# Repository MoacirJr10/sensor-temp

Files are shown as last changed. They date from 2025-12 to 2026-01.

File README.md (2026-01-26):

# Estação Híbrida de Monitoramento
### Monitoramento de Ar e Aquário com ESP8266

---

## Visão Geral
Estação de monitoramento inteligente baseada no **ESP8266 (Wemos D1 Mini)**, capaz de medir:

-  Temperatura e umidade do ar (DHT11)
-  Temperatura da água do aquário (DS18B20)
-  Hora e data (RTC + NTP)
-  Status de conexão WiFi

Todas as informações são exibidas em um **display LCD 20x4**.

---
## Conexões Elétricas

| Componente | Pino do Componente | Pino no Wemos D1 Mini | Nota Importante |
| --- | --- | --- | --- |
| **DS18B20 (Aquário)** | VCC (Vermelho) | 3.3V | Resistor **4.7kΩ** entre VCC e DATA |
| | GND (Preto) | GND | — |
| | DATA (Amarelo) | D3 | Protocolo **OneWire** |
| **DHT11 (Ar)** | VCC | 3.3V ou 5V | Funciona em ambas tensões |
| | GND | GND | — |
| | DATA | D4 | — |
| **LCD 20x4 I2C** | VCC | 5V | Melhor contraste |
| | GND | GND | — |
| | SDA | D2 | Comunicação I2C |
| | SCL | D1 | Comunicação I2C |
| **RTC DS1302** | VCC | 5V ou 3.3V | Depende do módulo |
| | GND | GND | — |
| | CLK | D5 | Clock |
| | DAT | D6 | Dados |
| | RST | D7 | Reset |

---

##  Galeria do Projeto
###  Case
<p align="center">
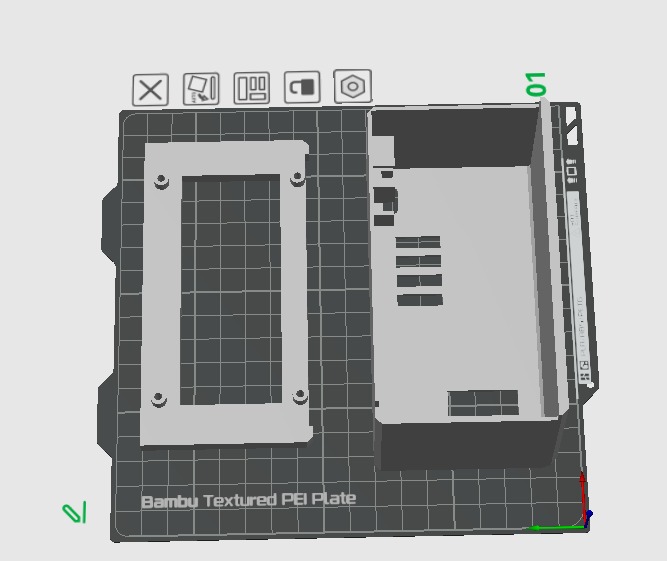
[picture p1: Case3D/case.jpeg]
  
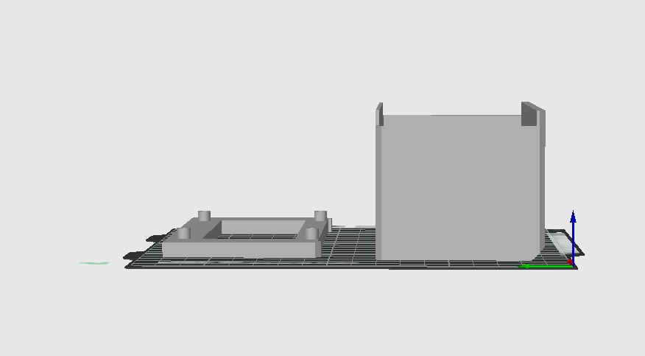
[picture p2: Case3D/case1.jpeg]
  
</p>

###  Detalhes 
<p align="center">
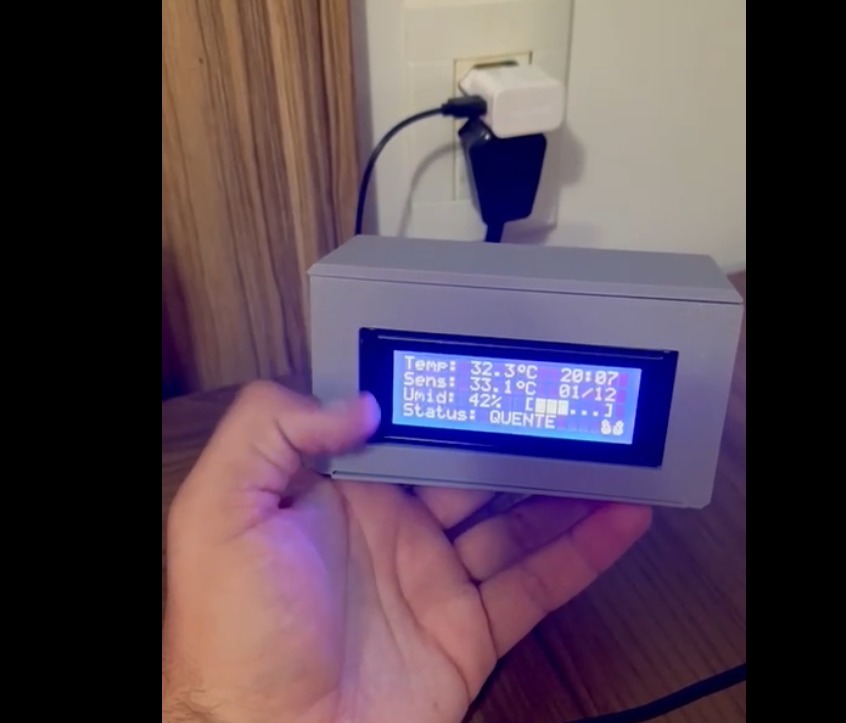
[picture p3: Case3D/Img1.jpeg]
  
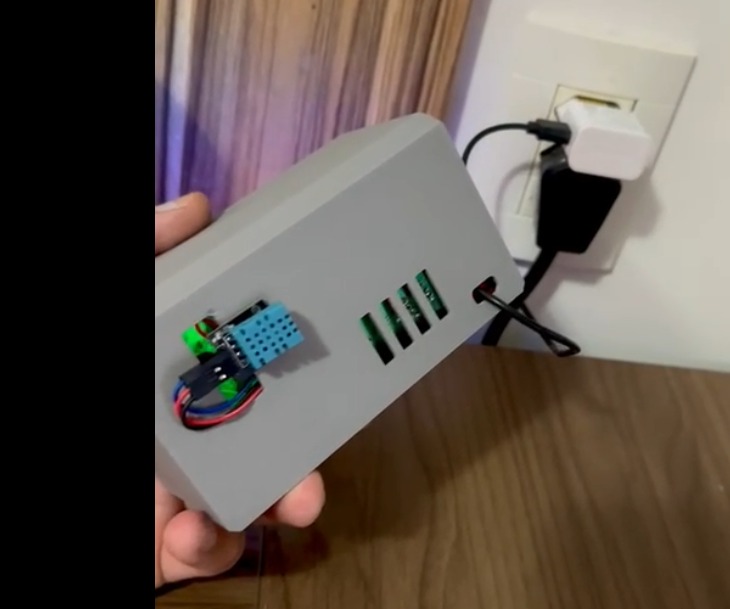
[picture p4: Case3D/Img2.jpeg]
  
</p>

---

##  Componentes Utilizados

| Componente | Função |
|---|---|
| Wemos D1 Mini (ESP8266) | Processamento e WiFi |
| Sensor DHT11 | Temperatura e umidade do ar |
| Sensor DS18B20 | Temperatura da água |
| Display LCD 20x4 I2C | Interface visual |
| RTC DS1302 | Data e hora |
| Resistor 4.7kΩ | Pull-up do DS18B20 |

---

##  Layout do Display LCD

| Linha | Conteúdo |
|-----|---|
| Linha 1 |  Temp. do Ar +  Hora |
| Linha 2 |  Temp. da Água +  Data |
| Linha 3 |  Umidade (%) + Barra |
| Linha 4 | Conforto +  WiFi + Emoji |

---

##  Pinagem – Wemos D1 Mini

| Pino | Ligação |
|----|---|
| D1 (SCL) | LCD I2C |
| D2 (SDA) | LCD I2C |
| D3 | DS18B20 (4.7kΩ → 3.3V) |
| D4 | DHT11 |
| D5 | RTC CLK |
| D6 | RTC DAT |
| D7 | RTC RST |

---

##  WiFi – Funcionamento Inteligente

| Recurso | Descrição |
|---|---|
| AP Temporário | `ESTACAO_AQUARIO` |
| Portal Ativo | 60 segundos |
| Modo Offline | Funciona sem WiFi |
| Reconexão | A cada 10 segundos |

---

##  Análise de Conforto

###  Temperatura do Ar
| Estado | Faixa |
|-----|---|
| FRIO | < 16 °C |
| NORMAL | 16–29 °C |
| QUENTE | > 29 °C |

###  Umidade
| Estado | Faixa |
|-----|---|
| Muito seco | < 30% |
| Normal | 30–75% |
| Muito úmido | > 75% |

---

##  Arquivos STL – Impressão 3D

 **Local:** `Case3D/stl/`

| Arquivo | Descrição |
|---|---|
| [`ArduBody.stl`](Case3D/stl/ArduBody.stl) | Corpo da estação |
| [`ArduLcdCover.stl`](Case3D/stl/ArduLcdCover.stl) | Moldura do LCD |

 Recomendações:
- Material: PLA ou PETG
- Infill: 20–30%
- Camada: 0.2 mm

---

##  Bibliotecas Necessárias

- DHT sensor library
- LiquidCrystal I2C
- Rtc by Makuna
- WiFiManager
- DallasTemperature
- OneWire

---

##  Instalação

1. Monte o hardware conforme a pinagem
2. Instale as bibliotecas
3. Grave o arquivo `sensor-temp.ino`
4. Ligue o sistema e configure o WiFi se desejar

---

##  Autor
**Moacir Pereira**  
 Eletrônica • Automação • Impressão 3D

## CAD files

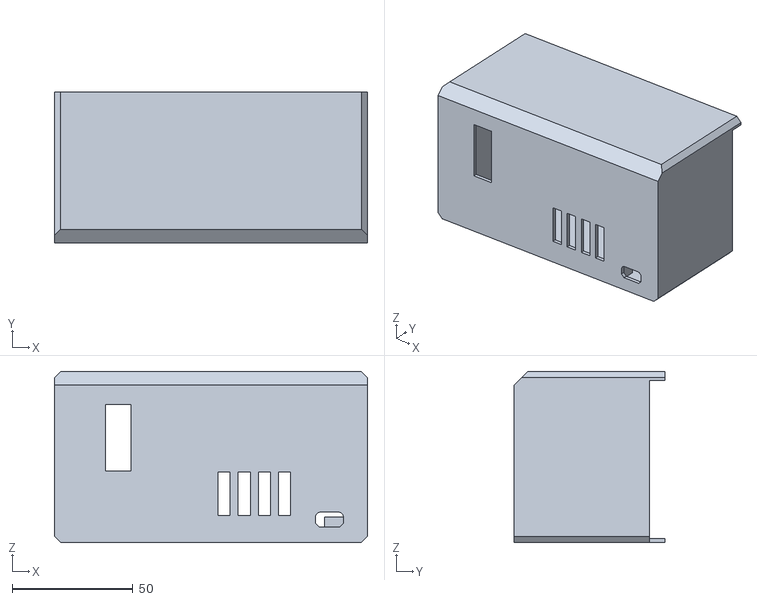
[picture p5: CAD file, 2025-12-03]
Case3D/stl/ArduBody.stl
129.4 x 62.4 x 70.7

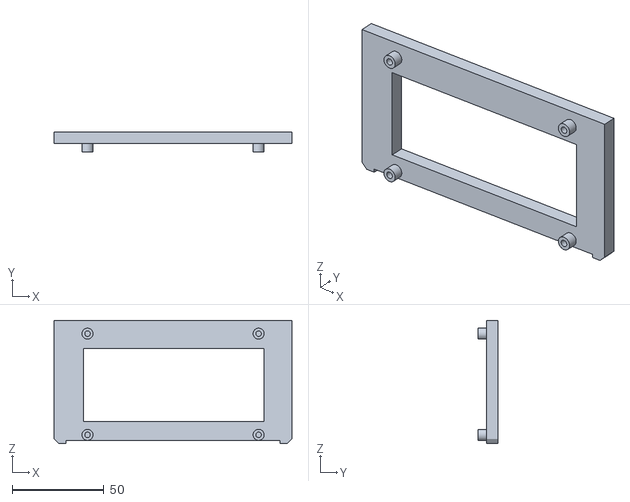
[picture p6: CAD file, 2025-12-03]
Case3D/stl/ArduLcdCover.stl
129.4 x 10.9 x 66.9

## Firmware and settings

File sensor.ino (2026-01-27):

#include <Wire.h>
#include <LiquidCrystal_I2C.h>
#include <DHT.h>
#include <ThreeWire.h>
#include <RtcDS1302.h>
#include <ESP8266WiFi.h>
#include <WiFiManager.h>
#include <OneWire.h>
#include <DallasTemperature.h>
#include <time.h>

// --- Hardware ---
#define DHTPIN D4
#define DHTTYPE DHT11
#define ONE_WIRE_BUS D3

OneWire oneWire(ONE_WIRE_BUS);
DallasTemperature sensors(&oneWire);
ThreeWire myWire(D6, D5, D7);
RtcDS1302<ThreeWire> rtc(myWire);
LiquidCrystal_I2C lcd(0x27, 20, 4);
DHT dht(DHTPIN, DHTTYPE);

// --- Variáveis ---
unsigned long ultimaLeitura  = 0;
unsigned long ultimaAnimacao = 0;
byte frame = 0;

// --- Ícones ---
byte grau[8] = {6,9,9,6,0,0,0,0};
byte wifiA[8] = {0,0,14,17,4,0,0,0};
byte wifiB[8] = {0,14,17,4,14,0,0,0};

byte coracaoA[8] = {0,10,31,31,31,14,4,0};
byte coracaoB[8] = {0,10,21,17,17,10,4,0};
byte fogoA[8]    = {4,10,10,21,21,31,31,14};
byte fogoB[8]    = {0,4,10,10,21,21,31,14};
byte neveA[8]    = {21,10,31,10,21,0,0,0};
byte neveB[8]    = {0,21,10,31,10,21,0,0};
byte gotaA[8]    = {4,4,14,14,31,31,31,14};
byte gotaB[8]    = {0,4,4,14,14,31,31,31};

// --- Ícones ---
void carregarIcones(byte f) {
  lcd.createChar(0, f ? coracaoA : coracaoB);
  lcd.createChar(1, f ? fogoA    : fogoB);
  lcd.createChar(2, f ? neveA    : neveB);
  lcd.createChar(3, f ? gotaA    : gotaB);
  lcd.createChar(4, f ? wifiA    : wifiB);
  lcd.createChar(7, grau);
}

// --- Sincroniza RTC via NTP ---
void sincronizarRTCviaWiFi() {
  configTime(-3 * 3600, 0, "pool.ntp.org", "time.nist.gov");

  time_t agora = time(nullptr);
  int tentativas = 0;

  while (agora < 100000 && tentativas < 20) {
    delay(500);
    agora = time(nullptr);
    tentativas++;
  }

  if (agora > 100000) {
    struct tm *t = localtime(&agora);
    rtc.SetDateTime(RtcDateTime(
      t->tm_year + 1900,
      t->tm_mon + 1,
      t->tm_mday,
      t->tm_hour,
      t->tm_min,
      t->tm_sec
    ));
  }
}

// --- SETUP ---
void setup() {
  Serial.begin(115200);

  lcd.init();
  lcd.backlight();
  carregarIcones(0);

  lcd.setCursor(0, 0);
  lcd.print("INICIALIZANDO...");

  // --- WiFi ---
  WiFi.mode(WIFI_STA);
  WiFi.disconnect(false);
  delay(300);

  WiFiManager wm;
  wm.setConfigPortalTimeout(180);
  wm.setBreakAfterConfig(true);
  wm.setDebugOutput(false);
  wm.autoConnect("ESTACAO_AQUARIO");

  // --- RTC ---
  rtc.Begin();

  if (WiFi.status() == WL_CONNECTED) {
    sincronizarRTCviaWiFi(); // 🕒 AJUSTE PERFEITO
  }

  if (!rtc.GetIsRunning()) {
    rtc.SetIsRunning(true);
  }

  dht.begin();
  sensors.begin();
  lcd.clear();
}

// --- LOOP ---
void loop() {
  unsigned long agora = millis();

  if (agora - ultimaLeitura >= 2000) {
    ultimaLeitura = agora;

    sensors.requestTemperatures();
    float tAgua = sensors.getTempCByIndex(0);
    float tAr   = dht.readTemperature();
    float h     = dht.readHumidity();
    float stAr  = dht.computeHeatIndex(tAr, h, false);

    lcd.setCursor(0, 0);
    lcd.print("Ar  : ");
    lcd.print(tAr, 1); lcd.write(7); lcd.print("C");

    lcd.setCursor(0, 1);
    lcd.print("Aqua: ");
    if (tAgua > -50) {
      lcd.print(tAgua, 1); lcd.write(7); lcd.print("C");
    } else lcd.print("ERR");

    lcd.setCursor(0, 2);
    lcd.print("Umid: ");
    lcd.print((int)h); lcd.print("%");
    if (h > 75) lcd.write(3); else lcd.print(" ");

    lcd.setCursor(12, 2);
    lcd.print("ST:");
    lcd.print(stAr, 0); lcd.write(7);

    lcd.setCursor(0, 3);
    lcd.print("Status: ");
    if (tAr > 29) {
      lcd.print("QUENTE "); lcd.write(1);
    } else if (tAr < 18) {
      lcd.print("FRIO   "); lcd.write(2);
    } else {
      lcd.print("BOM    "); lcd.write(0);
    }

    RtcDateTime now = rtc.GetDateTime();
    char hStr[6], dStr[6];
    snprintf(hStr, sizeof(hStr), "%02d:%02d", now.Hour(), now.Minute());
    snprintf(dStr, sizeof(dStr), "%02d/%02d", now.Day(), now.Month());

    lcd.setCursor(15, 0); lcd.print(hStr);
    lcd.setCursor(15, 1); lcd.print(dStr);
  }

  if (agora - ultimaAnimacao >= 600) {
    ultimaAnimacao = agora;
    frame = !frame;
    carregarIcones(frame);

    lcd.setCursor(18, 3);
    if (WiFi.status() == WL_CONNECTED) lcd.write(4);
    else lcd.print("X");
  }
}

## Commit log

2025-11-27 Refactor sensor.ino for clarity and efficiency
    Refactor sensor code for improved readability and performance. Update variable initialization and streamline logic for reading sensor data.
2025-11-27 Replace animated bitmaps for comfort states
    [sensor.ino]
2025-11-27 Revise README com melhorias e atualizações
    Atualiza a descrição do projeto e suas funcionalidades, adiciona novos componentes e detalha as ligações dos componentes. Inclui instruções de configuração e solução de problemas.
2025-12-02 Refactor sensor.ino for improved readability and structure
2025-12-03 adição de imagens e aqrquivos de stl para impressão 3d
    [ArduBody.stl, ArduLcdCover.stl]
